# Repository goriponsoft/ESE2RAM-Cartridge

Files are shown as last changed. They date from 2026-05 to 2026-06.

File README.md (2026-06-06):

# 似非²RAMカートリッジ(1Mbyte版)
[English README is here](README-en.md)

<!--
>>[!IMPORTANT]
>Rev.7で回路に大幅な改修が入ったため、Rev.6以前の基板をRev.7相当に改修する[基板改修情報](upgrade_patch/main.md)を公開しています。Rev.6以前の基板はMSX本体に負担を掛ける回路でしたので、この改修を行うことを強く推奨します。
-->




これは、汎用ロジックICによりメガROMコントローラと同等の動作を実現し、それを利用して似非RAMを構築したMSX用カートリッジ(命名:似非・似非RAMまたは似非²RAM)です。
ごりぽんハードウェア(同人サークル・ごりぽんソフトウェアのハードウェア部門)により作成されました。

KiCAD7用の回路図データ・基板データ・ガーバーデータを、クリエイティブ・コモンズライセンス(CC-BY-NC)で公開しています。
[MGINST215.zip](https://github.com/goriponsoft/ESE2RAM-Cartridge-74670/blob/main/MGINST215.zip)および[KSAVER105.zip](https://github.com/goriponsoft/ESE2RAM-Cartridge-74670/blob/main/KSAVER105.zip)はCCライセンスの対象ではなく、元のライセンスと条件が適用されます。

X(旧Twitter): @goriponsoft

## 似非RAMディスク(似非RAM)とは？

[同人サークル・似非職人工房](http://www.hat.hi-ho.ne.jp/tujikawa/ese/)のつじかわ氏が考案した、ストレージなどとして使えるMSX用の汎用バックアップRAMカートリッジです。

通常は、ゲームのメガROMカートリッジを改造し、ROMをRAMに置き換えることで制作します。MGINSTコマンドによりDOSカーネルをインストールしてSSDのようなストレージとして利用したり(似非RAMディスク)、メガROMのイメージを書き込んで動作させたりすることができます。

もともとストレージとしての使用を前提に考案されたため、カートリッジ自体も「似非RAMディスク」と呼ぶほうが一般的です。

なお、所有していないゲームのイメージを書き込んで動作させることは違法行為です。通常は似非RAMディスクの他、似非RAMに改造することで使用できなくなる改造元ゲームカートリッジのイメージ(改造前にファイルに書き出しておく必要あり)、フリーウェア、自作ROMゲーム、などを動作させるのに使用します。

似非RAMディスクについての詳細は、[似非職人工房の似非RAMディスクのページ](http://www.hat.hi-ho.ne.jp/tujikawa/ese/eseram.html)を参照してください。

## 似非²RAM(似非・似非RAM)とは？

近年MSXゲームの入手自体が難しくなり、貴重になってしまったメガROMカートリッジを潰して似非RAMにするのはかなり躊躇われる状況でした。そこで、普通に入手できる汎用ロジックICを使い、メガROMコントローラーと同等の回路を実現し、それを利用して似非RAMとして組み上げたのがこのカートリッジです。

似非RAMでありながら、メガROMコントローラを使用していない「似て非なる似非RAM」ということで「似非・似非RAM」、転じて「似非の2乗」で「似非²RAM」と命名しました。「次世代(第2世代)の似非RAM」という意味も込めています。上付き文字の使用に問題がある場合は「似非2RAM」や「似非似非RAM」でも構いません。英語表記は「ESE-ESE-RAM」または「ESE2-RAM」です。

## 部品表
注意: 基板Rev.6以降U3～U5が74HCシリーズから74AHCシリーズに変更、Rev.7以降はそれに加え抵抗・コンデンサ・ダイオードが変更されています
|部品番号|内容|数量|
|:--|:--|--:|
|BT1|CR2032電池ホルダ "CH29-2032LF"/"CH28-2032LF(TR)"/"CH004-2032LF"/"CH004-2032LF"のいずれか|1|
|C1-C8|積層セラミックコンデンサ 0.1μF・50V・2.5mmピッチ|8|
|C9|積層セラミックコンデンサ 100pF・50V・5mmピッチ|1|
|C10-C11|電解コンデンサ 47μF・6.3V以上・2mmピッチ|2|
|D1-D3|ショットキーバリアダイオード "BAT43"<br>※順方向電圧の低いダイオード|3|
|IC1-IC2|4Mbit SRAM(628512タイプ・512K×8bit) DIP-32 "AS6C4008"など|2|
|R1-R2|抵抗 10KΩ・1/4W|2|
|R3|抵抗 3.3KΩ・1/4W|1|
|RN1|集合抵抗 8素子・10KΩ SIP-9|1|
|S1|6×6mm タクトスイッチ "TVDP01-095BB1"|1|
|U1-U2|汎用ロジックIC "74HC670"|2|
|U3|汎用ロジックIC "74AHC138"|1|
|U4|汎用ロジックIC "74AHC00"|1|
|U5|汎用ロジックIC "74AHC32"|1|
|-|CR2032電池|1|

## 組み立て方
基板の実装面積の関係で、抵抗、コンデンサ、ダイオードなどの部品が裏面(ハンダ面)に配置されているため、組み立てには注意が必要です。

[詳細な組み立てマニュアル(日本語版)はこちら](assemble_manual/main.md)

1. 基板を裏返して(コネクタの傍に「Front」と書かれている側が表面です)、シルク印刷を参考に、ダイオード、抵抗、セラミックコンデンサ、電解コンデンサ、集合抵抗、の順で部品を配置して表側(部品面)からハンダ付けします。電解コンデンサはシルク印刷の方向に横倒しにして実装してください(縦に実装するとカートリッジシェルに収まりません)。ハンダを盛りすぎると、ICと基板の間に隙間ができるので、ハンダの量は控えめにしてハンダ付けしてください。
2. ハンダ付けしたら、表面に余ったリードを切断します。リードが余分に残っていると、やはりICと基板の間に隙間ができるので、こちらもできるだけ短くなるように切断してください。
3. 基板を表に戻し、ICを配置し、通常通り裏面(ハンダ面)からハンダ付けしていきます。ICのリードの処理は通常通りで構いません。
4. タクトスイッチと電池ホルダをハンダ付けします。
5. ショートや部品の付け間違いがないことを念入りに確認したうえで、MSX実機に挿して動作を確認します。似非RAMディスクとして使わない場合でも、動作確認にはMGINSTを使うのが簡単です。

## 準備 (似非RAMディスクとして使う場合)
1. 似非インストーラー(MGINST.COM)とカーネルセーバー(KSAVER.COM)を入手します。<br>※[似非職人工房・非公認出張所(似非なページ)](http://www.big.or.jp/~saibara/msx/ese/index-j.html)よりLHA形式のアーカイブをダウンロードすることができます。また、ZIP形式にアーカイブしなおした[MGINST215.zip](https://github.com/goriponsoft/ESE2RAM-Cartridge-74670/blob/main/MGINST215.zip)と[KSAVER105.zip](https://github.com/goriponsoft/ESE2RAM-Cartridge-74670/blob/main/KSAVER105.zip)も、こちらで用意してあります。
2. 何らかのMSXで起動可能なストレージ(通常はフロッピーディスク)に上記ツールを展開したものと、MSX-DOSのシステムファイル(MSXDOS.SYS/COMMAND.COM)をコピーします。MSX-DOS2カーネル利用の場合は、加えてMSX-DOS2のシステムファイル(MSXDOS2.SYS/COMMAND2.COM)をコピーしておくと、似非RAMインストール時に自動的にコピーされ、MSX-DOS2で起動することができるようになります。
3. MSX実機に似非²RAMカートリッジを挿し、タクトスイッチを押したまま電源を入れ、手順2で作成したストレージからMSX-DOS(またはMSX-DOS2)を起動します。
4. KSAVER.COMを使用し、MSX本体からMSX-DOSまたはMSX-DOS2のカーネルをファイルに保存します(詳細はKSAVERの付属ドキュメントを参照)。
5. MGINST.COMを使用し、手順4で保存したカーネルのファイルを指定して似非RAMカーネルをインストールします(詳細はMGINSTの付属ドキュメントを参照)。
6. リセットし似非RAMディスクから起動することを確認します。

手順4で保存したカーネルファイルは不要ですので、削除してしまっても構いません。残しておくと、似非RAMディスクの再インストール時に手順を省略できます。

手順5でエラーが出る場合は、部品のハンダ付け不良の可能性が高いので、基板をチェックしてみてください。

## 使い方 (メガROMソフトウェアを動かす場合)
使用した部品の機能の関係で、当カートリッジでは、セグメント番号の初期値がASCIIマッパーと異なっているため、プログラムによるレジスタの初期化が必須となっています。似非RAMディスクやゲームを含む、ほとんどのメガROMソフトウェアでは適切に初期化が行われているので問題ありませんが、初期化を怠っていたり、セグメント初期値が特定の値であることを期待しているソフトウェアは動作しない場合があります。

当カートリッジの起動直後もしくはリセット直後のバンクは以下のようになっています。

|バンクアドレス|レジスタアドレス|セグメント番号|
|:--|:--|--:|
|4000h-5FFFh|6000h-67FFh|0|
|6000h-7FFFh|6800h-6FFFh|0|
|8000h-9FFFh|7000h-77FFh|0|
|A000h-BFFFh|7800h-7FFFh|0|

当カートリッジでセグメント番号レジスタに採用しているICの74HC670には値をリセットする機能がなく、起動直後は全てのセグメント番号が不定値(リセットの場合はリセット直前の値)となってしまうため、4000h-5FFFhに正しくセグメント番号0のROMヘッダが現れるよう「起動後にレジスタアドレスに初回の書き込みが行われるまでは全てのバンクをセグメント番号0に固定する」という仕組みになっています。

この状態からレジスタアドレスに値を書き込むと、セグメント番号の固定が解除され、書き込んだレジスタは書き込んだセグメント番号に、書き込まれていないレジスタは本来のセグメント番号不定の状態に戻ります。

例えば6000hに0を書き込んだ場合は以下のようになります。

|バンクアドレス|セグメント番号|
|:--|--:|
|4000h-5FFFh|0|
|6000h-7FFFh|不定|
|8000h-9FFFh|不定|
|A000h-BFFFh|不定|

このため、当カートリッジで自作メガROMソフトウェアを動作させる場合は、INITエントリのできるだけ早い段階で、実行中のアドレスを含むバンクのレジスタに0を書き込んで初期化する必要があります。実行中のアドレスを含まないバンクのレジスタに先に書き込んでしまうと、実行中のプログラムが不定のバンクに切り替わり、ほとんどの場合は暴走します。また、書き込まれなかったレジスタの値は不定ですので、必要であれば初期化を行ってください。

通常はセグメント#0に以下のコードを配置し、ROMヘッダのINITエントリより4000h～5FFFhバンクの該当アドレスを呼び出せば、問題なく初期化できます。
```
	xor		a
	ld		(6000h),a
	ld		(6800h),a
	ld		(7000h),a
	ld		(7800h),a
```

## 互換性情報
動作確認済のハードウェア(順不同)について

ご報告いただいたものは順次追加・変更していきます

注意：作者所有の個体で動作した、もしくは動作報告者所有の個体で動作した、機種名を記載していますが、同一機種であっても全ての個体での動作を保証するものではありません。経年劣化や個体差により、動作しないことも、またその逆も有り得ます。

### 動作不良が確認されている機種と症状

- ビクター HC-90 および HC-95: 当カートリッジに書き込まれたデータが壊れるため正常動作しない
- 東芝 HX-E601(拡張スロット) : 認識されず起動しない
- 8086YES! OneChipBook および MSXBOOK: 当カートリッジに書き込まれたデータが壊れるため正常動作しない

### 正常動作が確認されている機種

- パナソニック FS-A1ST
- パナソニック FS-A1WX and FS-A1FX, FS-A1WSX
- パナソニック FS-A1, FS-A1F
- ナショナル FS-4700
- ナショナル CF-2000, CF-2700, CF-3000 および CF-3300
- ソニー HB-F1XV および HB-F1XDJ
- ソニー HB-201
- ヤマハ YIS503 および CX5F
- ヤマハ YIS604/128 および CX7M/128
- 三洋 MPC-2(WAVY2)
- 三洋 PHC-23J(WAVY23)
- 三洋 PHC-70FD(WAVY70FD) および PHC-70FD2(WAVY70FD2)
- 東芝 HX-31
- 東芝 HX-10D および HX-10S
- パイオニア PX-V7、PX-V60
- 三菱 ML-8000
- 三菱 ML-G30 model1 および ML-G30 model2
- ビクター HC-7
- ビクター HC-80
- キヤノン V-20
- カシオ PV-7, PV-16, MX-10
- カシオ KB-7(expansion slot)
- ゼネラル PCT-50 および PCT-55
- ソニー HB-F500 ※ただし似非RAMディスクとしての使用には難あり
- アスキーソリューションズ 1chipMSX ※ただし似非RAMディスクとしての使用には難あり

### 調査中の機種

- フロンロライン エキスパンションスロット(拡張スロット)
- パナソニック FS-A1FM
- カシオ MX-101
- 東芝 HX-20
- 東芝 HX-30

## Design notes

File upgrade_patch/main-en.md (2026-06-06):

# Circuit board modification information

This information concerns upgrading circuit boards from Rev.6 and earlier to Rev.7 equivalent.
Previous Rev.6 boards had circuits that put a strain on the MSX console, so this upgrade is strongly recommended.
<br>This will make the circuit equivalent to Rev.7, reducing the strain on the console, improving battery life, and enhancing compatibility.
The modification involves two stages: patching the circuit board to create a circuit equivalent to Rev.7 by using jumpers, pattern cuts, and discrete components, and replacing the IC. There are three possible modification methods: performing only one of these steps, or performing both.
<br>However, because the former patching involves soldering jumpers and discrete components to the IC pins, if you patch first, you may need to remove the patch once it's installed. Therefore, if you plan to replace the IC, it is recommended to do so first.

>[!IMPORTANT]
>The actual modification has been verified on Rev.4 to Rev.6 circuit boards. It may not be possible to modify Rev.3 or earlier circuit boards using the same procedure.

## Parts list
|Contents|Quantity|
|:--|--:|
|Resistor 3.3K ohm, 1/4W|1|
|Resistor 10K ohm, 1/4W<br>*Not required if the removed items are to be reused.|1|
|Schottky barrier diode BAT43<br>*If a replacement is needed, please select a diode with a low forward voltage (Vf) (usually a Schottky barrier diode).|5|
|MLCC 100pF, 50V|1|
|EC 47uF, 6.3V or higher|1|
|Logic IC "74ACT138"<br>*If you want to replace the IC|1|
|jumper wire|Appropriately|

## Circuit board modification procedure

Here are the actual repair procedures.

0. IC replacement
<br>We will remove the U3 and replace it with an IC from the ACT family that we have prepared.
- Remove the part enclosed by the orange line (one location) and replace it from 74AHC138 to 74ACT138.
- While replacing the ICs will provide maximum compatibility, it is usually not necessary. For models that operate faster than standard MSX (such as the FS-A1FX/WX/WSX in 5.37MHz mode or the HC-90/95 in turbo mode), models with different bus timing than standard MSX (such as the 1chipMSX series or the HC-90/95), or models with different signal drive voltages than standard MSX (such as the 1chipMSX series), compatibility may be further improved compared to modifications alone. Please choose the appropriate option based on the machine you are using.

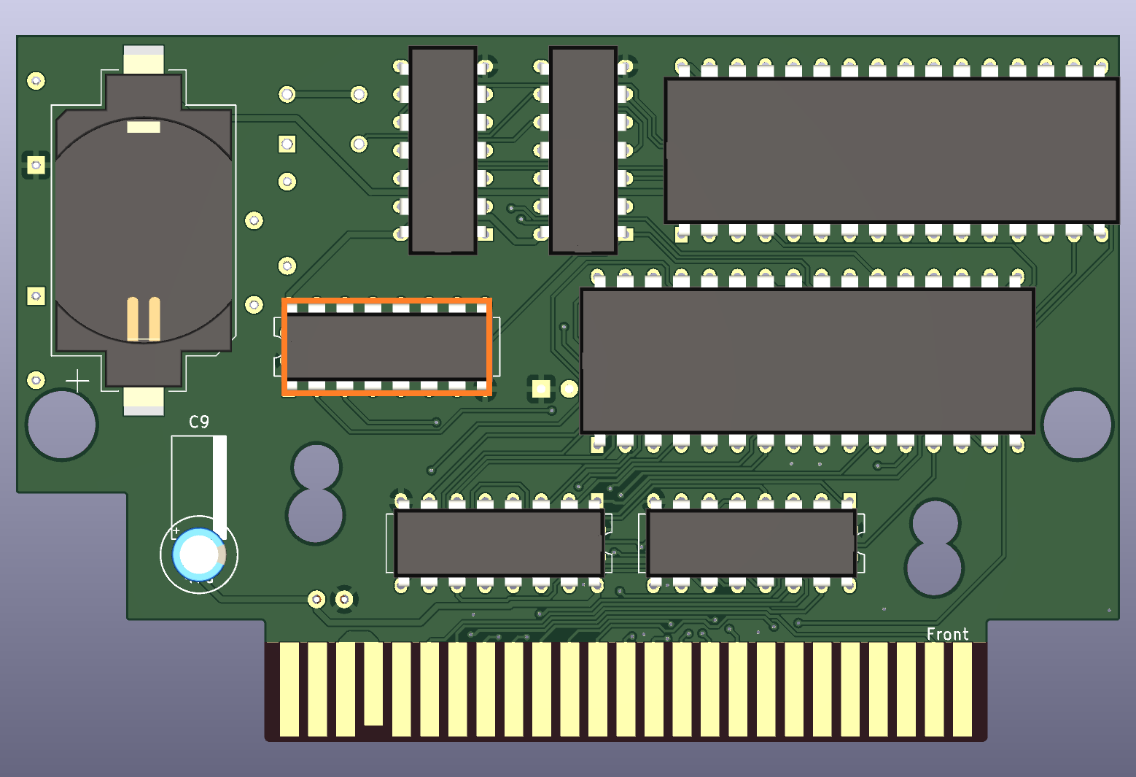
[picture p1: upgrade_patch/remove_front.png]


1. Pattern cutting (front side of circuit board)
<br>Perform pattern cutting.
- Cut the patterns indicated by the red lines (two locations) in the image.

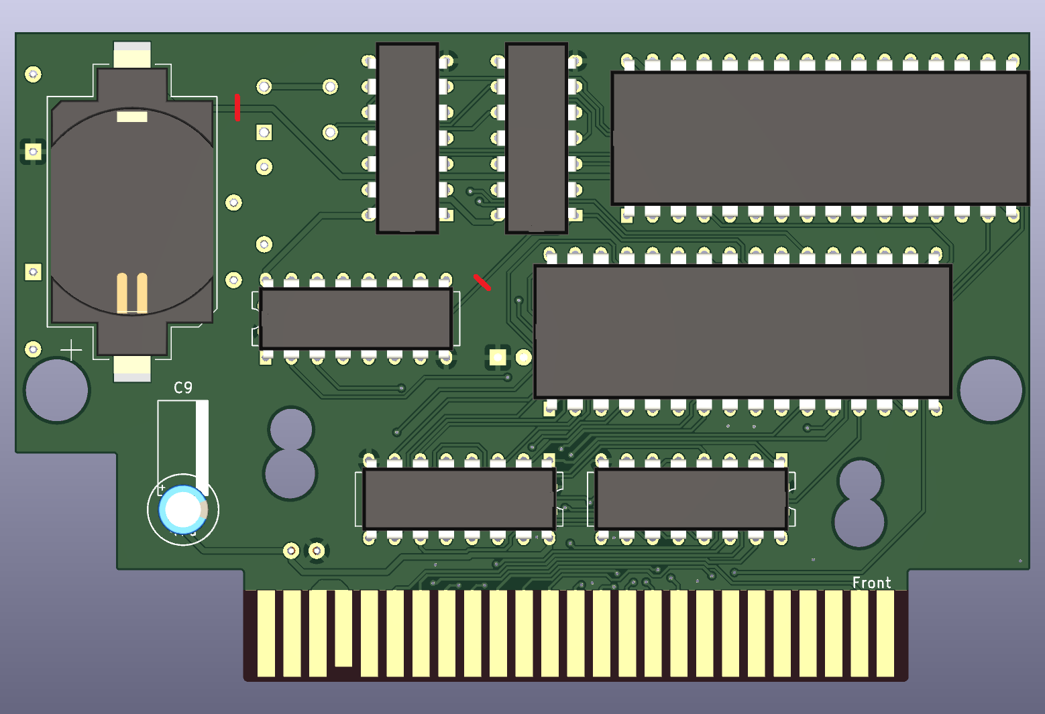
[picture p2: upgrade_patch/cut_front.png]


2. Pattern cutting and component removal (backside of circuit board)
<br>Similar to the front side, pattern cutting will be performed, and in addition, D1, D2, R1, R3, R4, and the jumper pins will be removed (the 1024KB/512KB switching jumper pin will become unusable after this modification).
- Cut along the red lines (9 locations) in the image, and remove the components (6 locations) enclosed by the orange lines.
- It may be difficult to see, but please note that there are also places to cut on the left side of R1 (between the left pad and the IC pins) and between the jumper pins (if jumper pins are installed, they should already be cut).

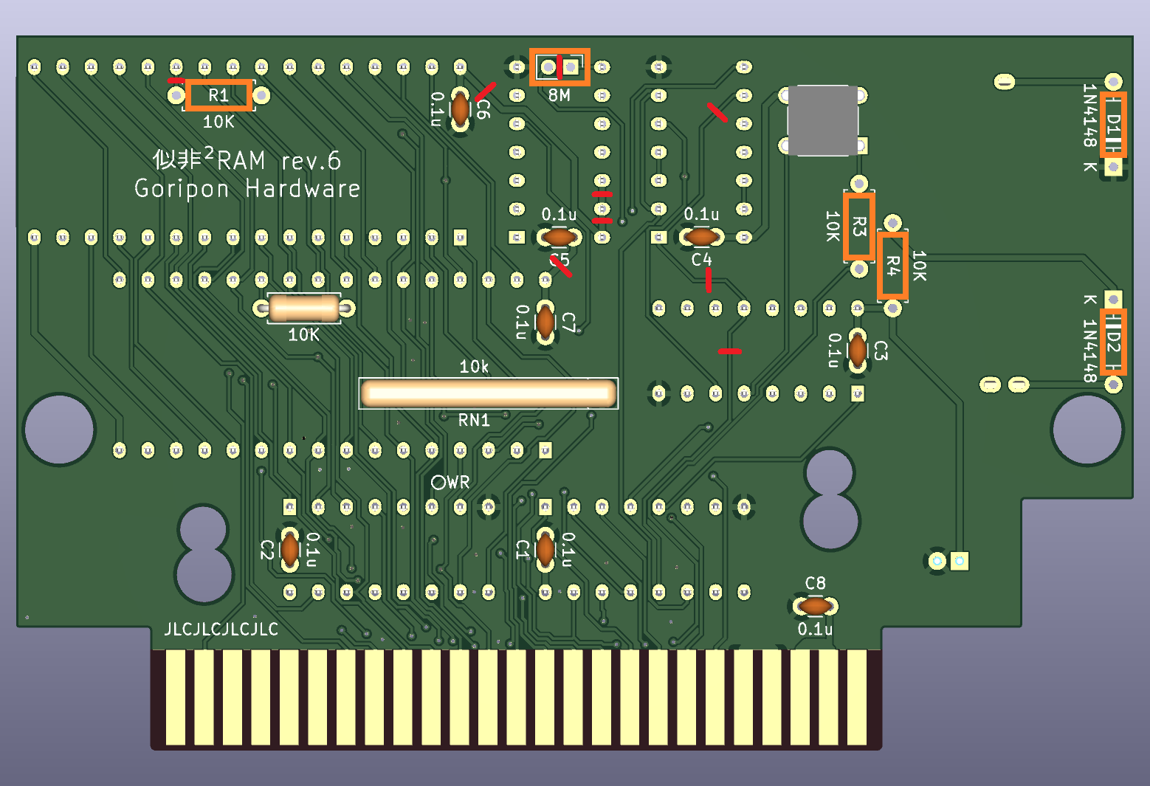
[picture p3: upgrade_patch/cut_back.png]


3.Jumper wiring (front side of circuit board)
<br>Based on the following wiring diagram, create a jumper (1 wire) using wiring material.
- Since this involves soldering to the terminals of the card edge connector, please take care to prevent too much solder from flowing by covering the terminals with heat-resistant tape or similar means.

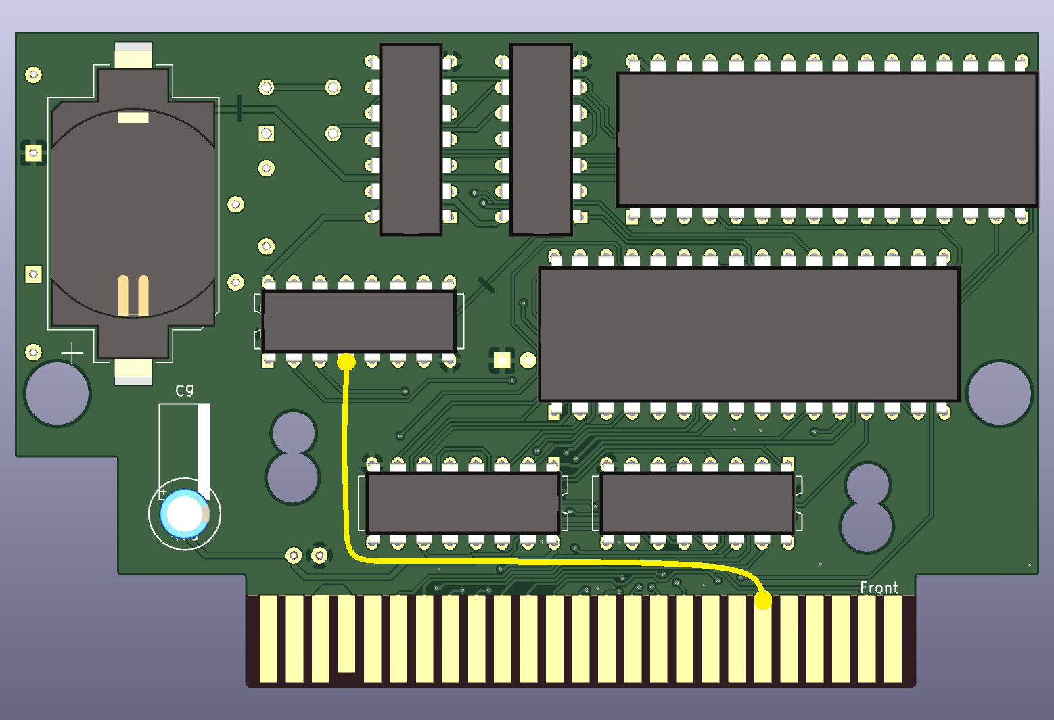
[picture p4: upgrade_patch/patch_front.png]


4. Component mounting and jumper wiring (backside of circuit board)
<br>Based on the following wiring diagram, place the components (9 locations) and connect the jumpers using wiring materials.
- Connect the cathode side of the BAT43 to the left pad of R1, and the anode side of the BAT43 to pin 22 of the SRAM (just above the left pad of R1). Connect one end of the 10kΩ resistor to the right pad of R1, and the other end of the resistor to the anode side of the BAT43.
- Replace R3 and R4 with BAT43 diodes (see image for orientation), replace D2 with a BAT43 diode (same orientation as the original), and bypass D1 by connecting it with wiring without placing any components.
- Connect the anode of the BAT43 to the left pad of the jumper pin (the side with the square silkscreen printing), and connect the cathode of the BAT43 to the right pad. If you install it vertically, it won't fit in the case, so please install it horizontally.
- Connect the 100pF MLCC in parallel with the BAT43 placed in the original R3 location.
- Connect the negative side of the 47uF EC to the original D1 cathode (GND) and the positive side to the D2 cathode. Please note that there is a protrusion on the inside of the case in the horizontal area around R3 and R4, so if you place electrolytic capacitors there, the case may not close properly.
- The connection of the SRAM pin on the far left of the physical wiring diagram is a reconnection to GND, so any GND will work, and in the physical wiring diagram, the solder mask of a nearby GND plane is scraped off and the connection is made there.

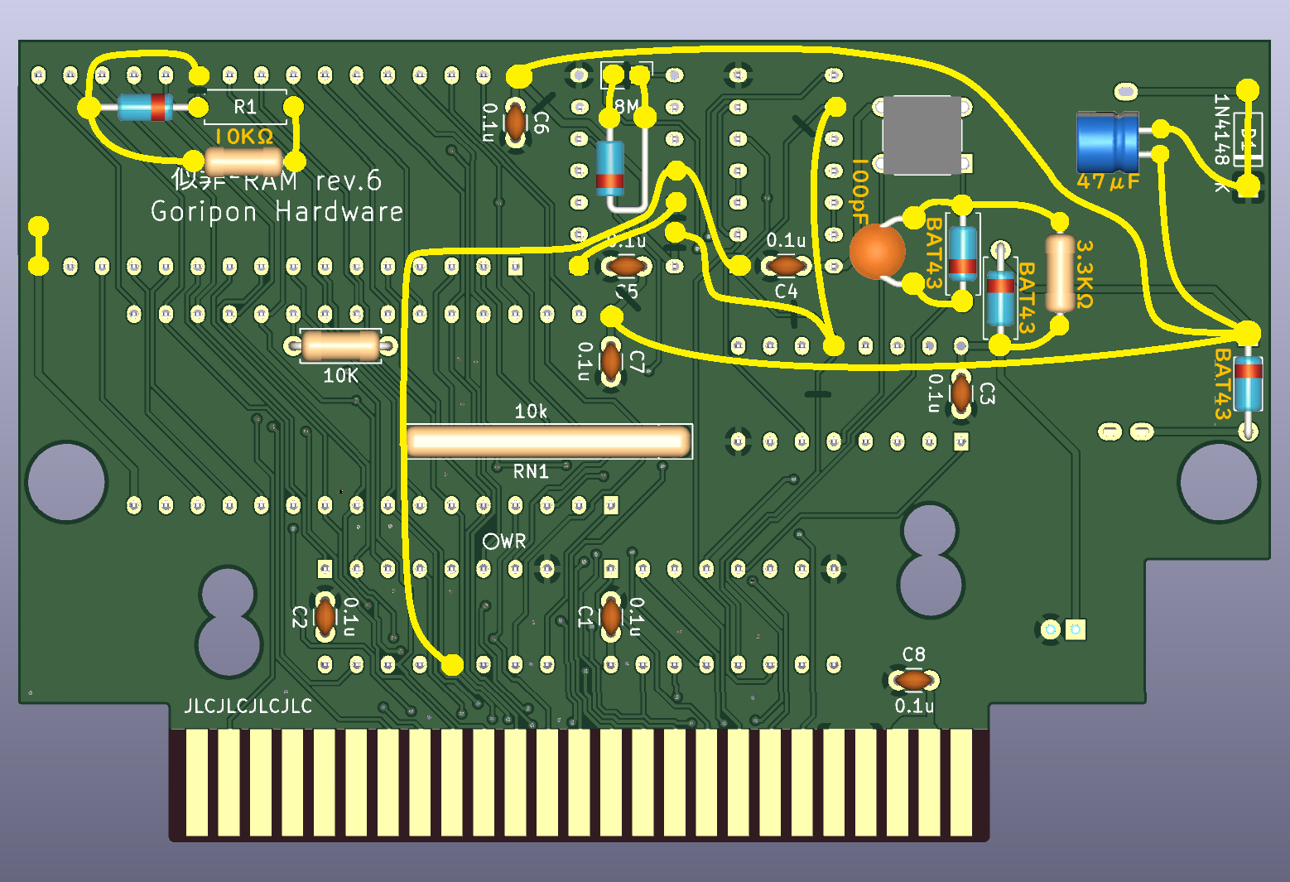
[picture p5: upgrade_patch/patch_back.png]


## Actual modification example

These are photos of the actual modification and verification process.

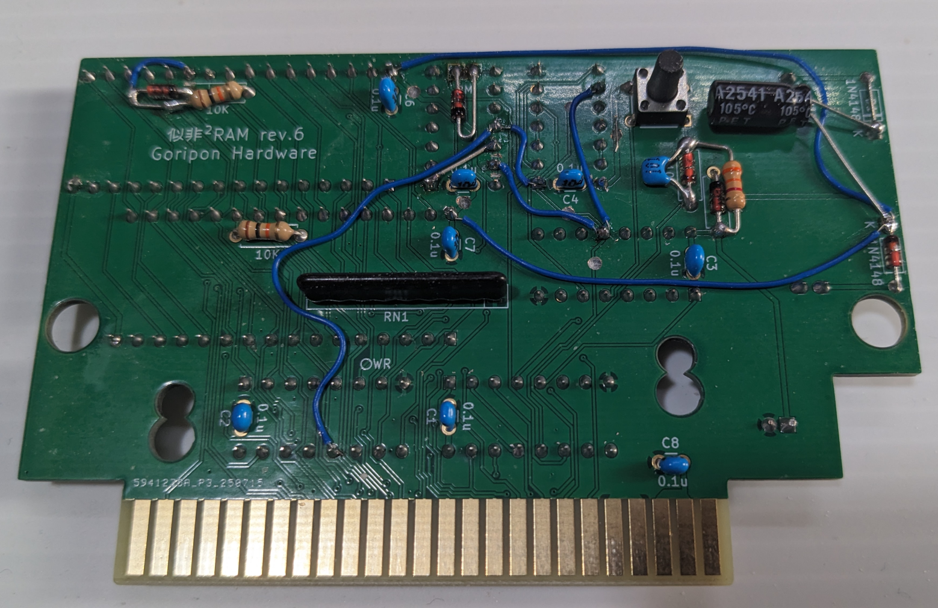
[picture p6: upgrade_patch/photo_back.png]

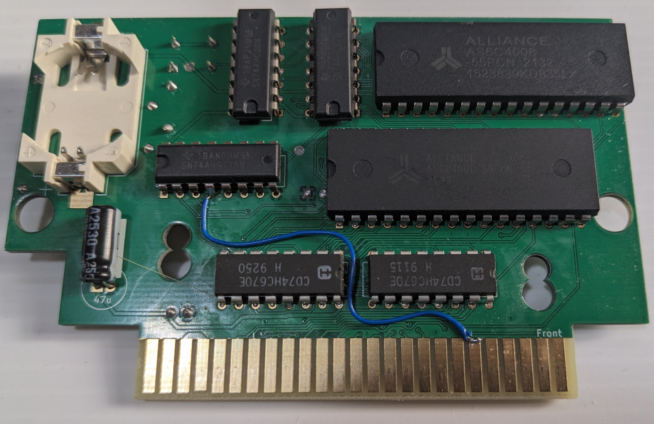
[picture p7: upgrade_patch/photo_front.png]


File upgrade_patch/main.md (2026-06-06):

# 基板改修情報

Rev.6以前の基板をRev.7相当の回路に改修するための情報です。
Rev.6以前の基板はMSX本体に負担を掛ける回路でしたので、この改修を行うことを強く推奨します。
<br>これにより、回路はRev.7と同等になり、本体への負担軽減のほか、電池保ちが改善され、互換性が向上します。

改修には、ジャンパ・パターンカット・ディスクリート部品搭載によりRev.7相当の回路にする基板へのパッチあてと、IC載せ替えの2段階があり、どちらか片方だけを行う、もしくは両方行う、合わせて3通りの改修方法があります。
<br>ただし、前者のパッチあてはICの足にジャンパやディスクリート部品をハンダ付けする都合上、先にパッチを行った場合は一旦取り付けたパッチを外さなければいけない場合があるため、ICの交換を行う場合は先に行うことを推奨します。

>[!IMPORTANT]
>実際の改修はRev.4～Rev.6の基板で検証しています。Rev.3以前の基板の場合は、同じ手順で改修出来ない可能性があります。

## 部品表

|内容|数量|
|:--|--:|
|抵抗 3.3KΩ・1/4W|1|
|抵抗 10KΩ・1/4W<br>※撤去したものを再利用する場合は不要|1|
|ショットキーバリアダイオード BAT43<br>※代替品になる場合は順方向電圧(Vf)の低いダイオード(通常はショットキーバリアダイオード)を選択してください|5|
|積層セラミックコンデンサ 100pF・50V|1|
|電解コンデンサ 47μF・6.3V以上|1|
|ロジックIC "74ACT138"<br>※ICを換装する場合|1|
|ジャンパ用配線|適宜|

## 改修手順

実際の改修手順です。

0. IC換装
<br>U3を撤去して、用意しておいたACTファミリーのICに換装します。
- 橙線で囲われている部品(1ヶ所)を撤去し、74AHC138から74ACT138に換装します。
- ICの換装により最大限の互換性が得られますが、通常ICの換装までは必要ありません。標準的なMSXより高速で動作する機種(FS-A1FX/WX/WSXの5.37MHzモード・HC-90/95ターボモード等)や、バスタイミングが標準的なMSXと異なる機種(1chipMSX系・HC-90/95等)、信号の駆動電圧が標準的なMSXと異なる機種(1chipMSX系)であれば、改修のみに比べ互換性が更に向上する可能性がありますので、使用する本体に合わせ適宜選択してください。



1. パターンカット(基板表面)
<br>パターンカットを行います。
- 画像の赤線(2ヶ所)のパターンをカットします。



2. パターンカットと部品撤去(基板裏面)
<br>表面と同様にパターンカットと、加えてD1、D2、R1、R3、R4、ジャンパピンの撤去を行います(1024KB/512KB切替ジャンパピンはこの改修で使えなくなります)。
- 画像の赤線(9ヶ所)のパターンをカットし、橙線で囲われている部品(6ヶ所)を撤去します。
- 判り難いですが、R1左側(左側パッドとICのピンの間)と、ジャンパピンの間(ジャンパピンが取り付けられている場合はカット済)にもカットする場所がありますので、ご注意ください。



3. ジャンパ配線(基板表面)
<br>以下の実体配線図をもとに、配線材でジャンパ(1配線)を飛ばします。
- カードエッジコネクタの端子へのハンダ付けになるため、耐熱テープで端子を覆うなどして、ハンダがあまり流れないよう注意して作業してください。



4. 部品取付とジャンパ配線(基板裏面)
<br>以下の実体配線図をもとに部品(9ヶ所)を載せて、配線材でジャンパを飛ばします。
- R1左側パッドにBAT43のカソード側を接続、BAT43のアノード側はSRAMの22ピン(R1左側パッドのすぐ上)に接続、R1右側パッドには10KΩの抵抗の片方を接続、抵抗のもう片方はBAT43のアノード側に接続します。
- R3、R4はダイオードBAT43(向きは画像を参照)に換装、D2も同じくBAT43(向きは元と同じ)に換装、D1には部品は載せず配線で繋いでバイパスします。
- ジャンパピンの左側パッド(四角のシルク印刷がある側)にBAT43のアノードを接続、右側パッドにBAT43のカソードを接続します。縦に取り付けるとケースに収まらなくなるため、寝かせて取り付けてください。
- 100pFの積層セラミックコンデンサは、元R3の場所に載せたBAT43と並列になるように繋ぎます。
- 47μFの電解コンデンサは、マイナス側を元D1のカソード(GND)に、プラス側をD2のカソードに繋ぎます。R3・R4付近の横一帯のエリアにはケース内側の凸部が来るため、電解コンデンサを置いてしまうとケースが閉まらなくなる可能性がありますので、ご注意ください。
- 実体配線図左端のSRAMのピンの接続はGNDへの繋ぎ替えなのでGNDであればどこでも問題なく、実体配線図では近くのベタGNDのレジストを削って繋いでいます。



## 実際の改修例

こちらで実際に改修して検証したものの写真になります。




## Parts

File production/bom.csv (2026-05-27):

Designator | Footprint | Quantity | Value | LCSC Part #
BT1 | BatteryHolder_CH2x-2032LF | 1 | CR2032
C1, C2, C3, C4, C5, C6, C7, C8 | C_Disc_D3.0mm_W1.6mm_P2.50mm | 8 | 0.1u
C10, C11 | CP_Radial_D5.0mm_P2.00mm_Horizontal | 2 | 47u
C9 | C_Disc_D4.3mm_W1.9mm_P5.00mm | 1 | 100p
D1, D2, D3 | D_DO-35_SOD27_P7.62mm_Horizontal | 3 | BAT43
IC1, IC2 | DIP32_600mil_FineLongPad | 2 | 4M SRAM
R1, R2 | R_Axial_DIN0207_L6.3mm_D2.5mm_P7.62mm_Horizontal | 2 | 10K
R3 | R_Axial_DIN0207_L6.3mm_D2.5mm_P7.62mm_Horizontal | 1 | 3.3K
RN1 | R_Array_SIP9 | 1 | 10k
S1 | TVDP01-095BB1 | 1 | TVDP01-095BB1
U1, U2 | DIP16_300mil_FineLongPad | 2 | 74HC670
U3 | DIP16_300mil_FineLongPad | 1 | 74AHC138
U4 | DIP14_300mil_FineLongPad | 1 | 74AHC00
U5 | DIP14_300mil_FineLongPad | 1 | 74AHC32

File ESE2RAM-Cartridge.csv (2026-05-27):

Source: | Y:\Project\ESE2RAM-Cartridge\ESE2RAM-Cartridge.kicad_sch
Date: | 2026/05/27 1:39:44
Tool: | Eeschema 7.0.11
Generator: | C:\Program Files\KiCad\7.0\bin\scripting\plugins/bom_csv_grouped_by_value_with_fp.py
Component Count: | 27
Ref | Qnty | Value | Cmp name | Footprint | Description | Vendor | DNP
BT1 | 1 | CR2032 | Battery_Cell | ProjectLibrary:BatteryHolder_CH2x-2032LF | Single-cell battery
C1, C2, C3, C4, C5, C6, C7, C8 | 8 | 0.1u | C_Small | Capacitor_THT:C_Disc_D3.0mm_W1.6mm_P2.50mm | Unpolarized capacitor, small symbol
C9 | 1 | 100p | C_Small | Capacitor_THT:C_Disc_D4.3mm_W1.9mm_P5.00mm | Unpolarized capacitor, small symbol
C10, C11 | 2 | 47u | C_Polarized_Small | ProjectLibrary:CP_Radial_D5.0mm_P2.00mm_Horizontal | Polarized capacitor, small symbol
D1, D2, D3 | 3 | BAT43 | BAT43 | Diode_THT:D_DO-35_SOD27_P7.62mm_Horizontal | 30V 0.2A Small Signal Schottky Diode, DO-35
IC1, IC2 | 2 | 4M SRAM | AS6C4008-55PIN | ProjectLibrary:DIP32_600mil_FineLongPad | SRAM 4M, 2.7-5.5V, 55ns 512K x 8 Asynch SRAM
R1, R2 | 2 | 10K | R_Small | Resistor_THT:R_Axial_DIN0207_L6.3mm_D2.5mm_P7.62mm_Horizontal | Resistor, small symbol
R3 | 1 | 3.3K | R_Small | Resistor_THT:R_Axial_DIN0207_L6.3mm_D2.5mm_P7.62mm_Horizontal | Resistor, small symbol
RN1 | 1 | 10k | R_Network08 | Resistor_THT:R_Array_SIP9 | 8 resistor network, star topology, bussed resistors, small symbol
S1 | 1 | TVDP01-095BB1 | TVDP01-095BB1 | _GoriponsoftLibrary:TVDP01-095BB1 | 6x6 Through Hole & Ground Terminal Type,TS 6MM V H=9.5 BULK
U1, U2 | 2 | 74HC670 | 74HC670 | ProjectLibrary:DIP16_300mil_FineLongPad | 4 x 4 Register Files Open Collector
U3 | 1 | 74AHC138 | 74AHC138 | ProjectLibrary:DIP16_300mil_FineLongPad | 3-to-8 line decoder/multiplexer inverting, DIP-16/SOIC-16/SSOP-16
U4 | 1 | 74AHC00 | 74AHC00 | ProjectLibrary:DIP14_300mil_FineLongPad | quad 2-input NAND gate
U5 | 1 | 74AHC32 | 74AHC32 | ProjectLibrary:DIP14_300mil_FineLongPad | Quad 2-input OR

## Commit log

2025-10-16 Modified README
    互換性情報セクションに動作確認情報を追加
    Added compatibility information to the Compatibility information section
    使い方セクションの内容を改定
    Updated the How to Use section
2025-10-16 Rename schematic
    [ESE2RAM-Cartridge.csv, ESE2RAM-Cartridge.kicad_pcb, ESE2RAM-Cartridge.kicad_sch]
2025-10-16 Changes related to filename renaming
    ファイル名変更に伴う回路図データの変更。
    Schematic-data changes due to file name changes.
    [ESE2RAM-Cartridge.csv, ESE2RAM-Cartridge.kicad_pcb, ESE2RAM-Cartridge.kicad_sch]
2025-10-17 Modified README
    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
2026-05-25 Updated schematic revision.
    バックアップ電源回路を改良しました
    Backup power supply circuit has been refined.
    カートリッジ無効化スイッチを改良しました
    Cartridge deactivation switch has been refined.
    アドレスデコーダを改良しました
    Address decoder has been refined.
    [ESE2RAM-Cartridge.kicad_pcb, ESE2RAM-Cartridge.kicad_sch, bom.csv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]
2026-05-27 Schematic data correction and addition of documentation.
    カートリッジ無効化ボタン周りの改修でコンデンサの追加を忘れていたので修正。
    I forgot to add a capacitor when modifying the area around the cartridge disable button, so I fixed that.
    基板改修情報のドキュメントを追加。
    Added a document titled "Circuit Board Modification Information".
    [ESE2RAM-Cartridge.csv, ESE2RAM-Cartridge.kicad_pcb, ESE2RAM-Cartridge.kicad_sch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]
2026-05-28 Correction of Schematic data and documents.
    アドレスデコード結果を反映させる対象がSRAMの/WE信号から/CE信号に変更された。
    The target to which the address decoding results are reflected has been changed from the SRAM's /WE signal to the /CE signal.
    基板改修情報のドキュメントを回路図に合わせ修正。
    The documentation for circuit board modification information has been revised to match the schematic.
    [ESE2RAM-Cartridge.kicad_pcb, ESE2RAM-Cartridge.kicad_sch]
2026-05-28 Revert "Correction of Schematic data and documents."
    This reverts commit bc8d3cb6dc4d5604d2b0a5969a538fbe96077484.
    [ESE2RAM-Cartridge.kicad_pcb, ESE2RAM-Cartridge.kicad_sch]
